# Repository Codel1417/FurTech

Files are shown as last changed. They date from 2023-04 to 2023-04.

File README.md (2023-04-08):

# FurTech

These are the files for a fursuit I am planning on making. I wanted eye displays for more expression, but then realized I cant see through the displays, Stereo cameras and an AR headset will be used for vision. The cameras will be hidden in the eyebrows. The jetson nano will handle stereo correction and managing the various sensors and servos. Once I have the hardware needed I will begin working on software. Base features are vision and ears reacting to sound. Then eye tracking using the cameras and opencv.

## Goals

* Eye Displays
* Ears which react to motion and environment
* Moving mouth to my voice
* Headpat detection and reactions
* Active cooling fan
* Stereo forward cameras
* AR/VR display for vision
* Eye Tracking (Vision or internal camera)
* No spaghetti 

## Hardware Features

Sensors connect over I2C

### Power Supply

* USB PD in @8-20V
* 3 5V 5A Linear Regulators
* Current Monitoring over I2C

### Sensors

* I2C Multiplexor
* Temperature Sensor
* 9-Axis IMU
* 5 Touch Sensors
* Cooling fan for comfort

### Ear Breakout

* Servo power switch
* i2C PWM Driver
* Mic/ADC input

### Display Driver

* 2 Display Connections
* Single output connection

### Jetson Nano Breakout

* I2C In
* Display SPI in
* Power in

## Other Hardware

* Nvidia Jetson Nano
* Nreal Air
* Stereo Cameras 1080P@60
* Usb PD battery
* 2x MatrixOrbital EVE3/4 displays
* 6x SG90 Servos

## 3D Printer STLs

* [https://www.thingiverse.com/thing:717901](https://www.thingiverse.com/thing:717901)

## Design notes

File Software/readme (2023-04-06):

Vision will be handled using GStreamer and OpenCV, in python. After coding and getting to a functional point I may switch to C/C++ for reduced power consumption.

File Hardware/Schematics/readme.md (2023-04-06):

The schematics were designed in [KiCad](https://www.kicad.org/) and use a consistent Resistor/Capacitor/LED size of 0603/1608 for ease of hand soldering. The AutoRouter plugin was used for data and low current traces. JST connectors are used to connect each board together.

Why split the boards? I was concerned about limited space inside the head so smaller boards let me contour the shape of the fursuit to reduce cable lengths and reduce the need to upscale the head. Smaller boards also allows for cheaper at con component swap out if something breaks.

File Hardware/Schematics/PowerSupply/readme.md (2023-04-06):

The original design was for an external 18650 battery pack but due to safety concerns I switched to USB C and premade packs.

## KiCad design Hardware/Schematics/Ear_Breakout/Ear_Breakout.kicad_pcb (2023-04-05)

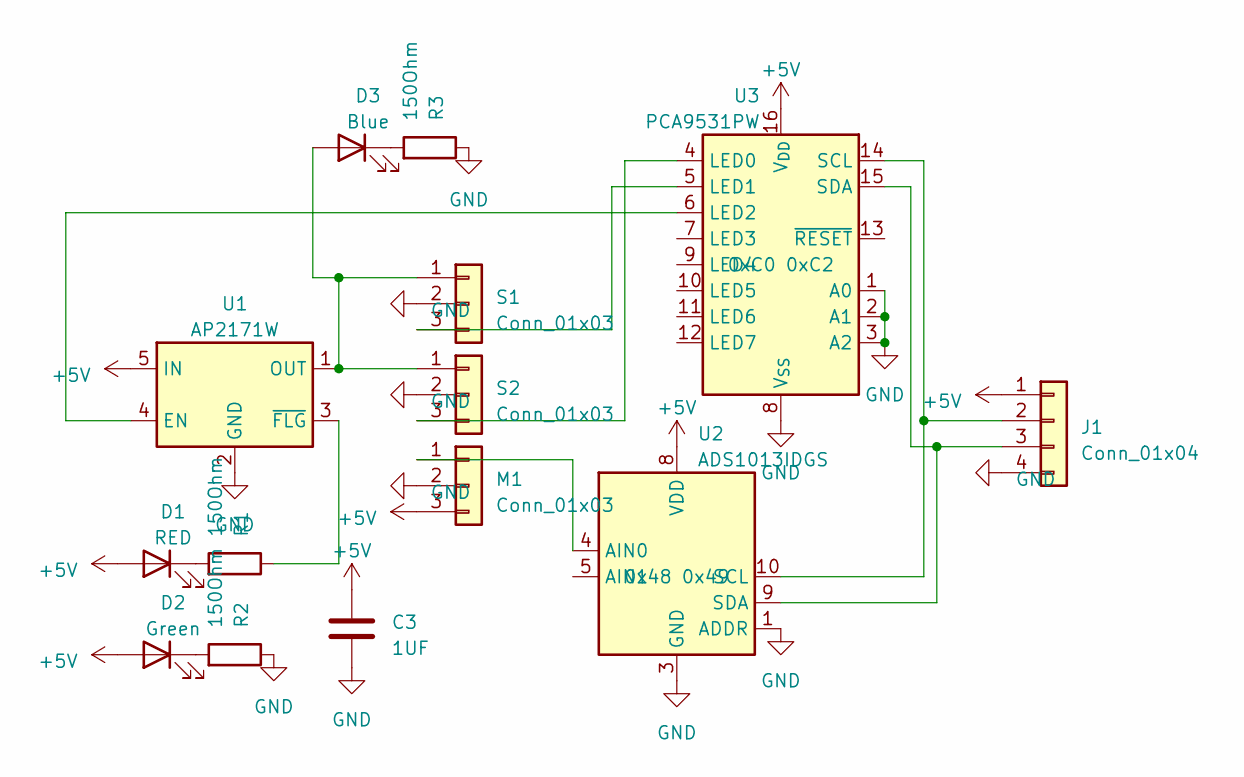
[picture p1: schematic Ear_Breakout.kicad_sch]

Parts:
C3: 1UF; C_0603_1608Metric_Pad1.08x0.95mm_HandSolder
D1: RED; LED_0603_1608Metric_Pad1.05x0.95mm_HandSolder
D2: Green; LED_0603_1608Metric_Pad1.05x0.95mm_HandSolder
D3: Blue; LED_0603_1608Metric_Pad1.05x0.95mm_HandSolder
J1: Conn_01x04; JST_EH_S4B-EH_1x04_P2.50mm_Horizontal
M1: Conn_01x03; PinHeader_1x03_P2.54mm_Horizontal
R1, R2, R3: 150Ohm; R_0603_1608Metric_Pad0.98x0.95mm_HandSolder
S1, S2: Conn_01x03; PinHeader_1x03_P2.54mm_Horizontal
U1: AP2171W; SOT-23-5
U2: ADS1013IDGS; TSSOP-10_3x3mm_P0.5mm
U3: PCA9531PW; TSSOP-16_4.4x5mm_P0.65mm

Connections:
+5V: C3.1, D1.2 (A), D2.2 (A), J1.1, M1.3, U1.5 (IN), U2.8 (VDD), U3.16 (V_{DD})
GND: C3.2, J1.4, M1.2, R2.1, R3.1, S1.2, S2.2, U1.2 (GND), U2.1 (ADDR), U2.3 (GND), U3.1 (A0), U3.2 (A1), U3.3 (A2), U3.8 (V_{SS})
unnamed: D1.1 (K), R1.2
unnamed: D2.1 (K), R2.2
unnamed: D3.2 (A), S1.1, S2.1, U1.1 (OUT)
unnamed: D3.1 (K), R3.2
unnamed: J1.2, U2.10 (SCL), U3.14 (SCL)
unnamed: J1.3, U2.9 (SDA), U3.15 (SDA)
unnamed: M1.1, U2.4 (AIN0)
unnamed: S1.3, U3.5 (LED1)
unnamed: S2.3, U3.4 (LED0)
unnamed: U1.4 (EN), U3.6 (LED2)
unnamed: R1.1, U1.3 (~FLG)

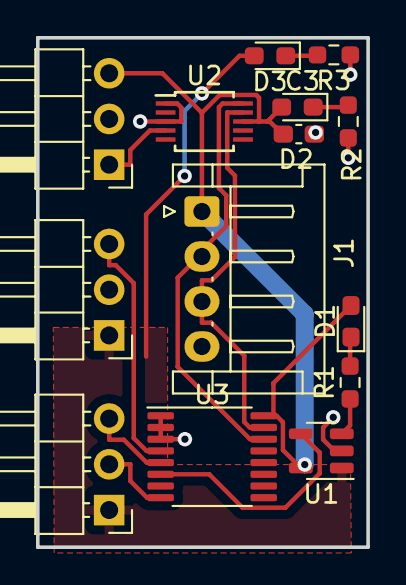
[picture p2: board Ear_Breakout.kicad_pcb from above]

Board: 2 copper layers, 18.3 x 28.3 mm, 14 parts (0 on the bottom side), 13 nets.

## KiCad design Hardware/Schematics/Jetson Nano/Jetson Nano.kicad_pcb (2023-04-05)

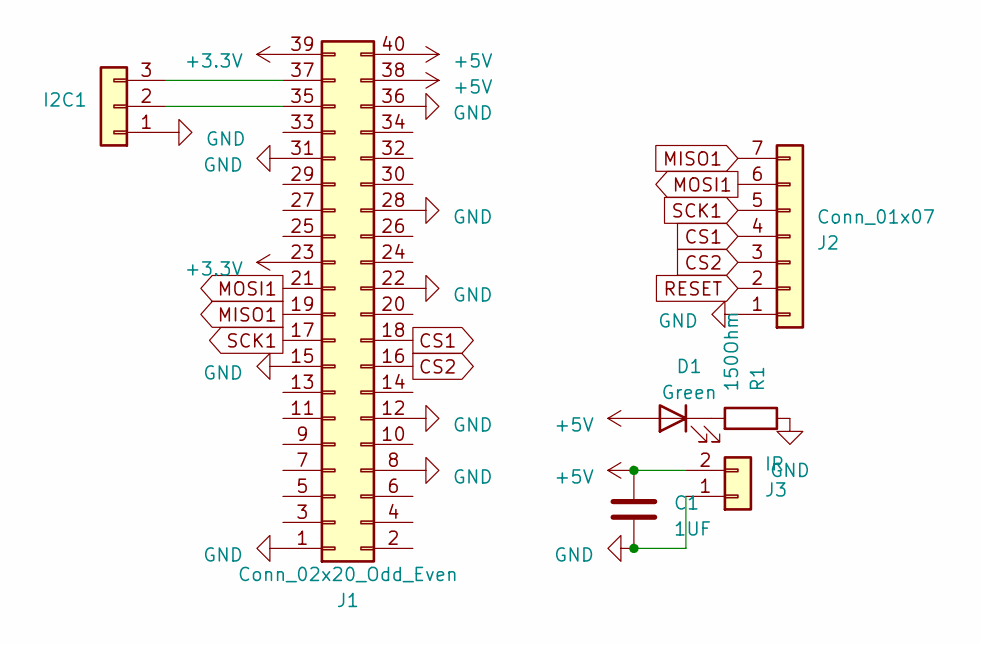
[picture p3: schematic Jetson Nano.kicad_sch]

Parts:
C1: 1UF; C_0603_1608Metric_Pad1.08x0.95mm_HandSolder
D1: Green; LED_0603_1608Metric_Pad1.05x0.95mm_HandSolder
I2C1: Conn_01x04; JST_EH_S3B-EH_1x03_P2.50mm_Horizontal
J1: Conn_02x20_Odd_Even; PinSocket_2x20_P2.54mm_Vertical
J2: Conn_01x07; JST_EH_S7B-EH_1x07_P2.50mm_Horizontal
J3: IR; JST_EH_S2B-EH_1x02_P2.50mm_Horizontal
R1: 150Ohm; R_0603_1608Metric_Pad0.98x0.95mm_HandSolder

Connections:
+3.3V: J1.23, J1.39
+5V: C1.1, D1.2 (A), J1.38, J1.40, J3.2
CS1: J1.18, J2.4
CS2: J1.16, J2.3
GND: C1.2, I2C1.1, J1.1, J1.8, J1.12, J1.15, J1.22, J1.28, J1.31, J1.36, J2.1, J3.1, R1.1
MISO1: J1.19, J2.7
MOSI1: J1.21, J2.6
unnamed: D1.1 (K), R1.2
unnamed: I2C1.2, J1.35
unnamed: I2C1.3, J1.37
RESET: J2.2
SCK1: J1.17, J2.5

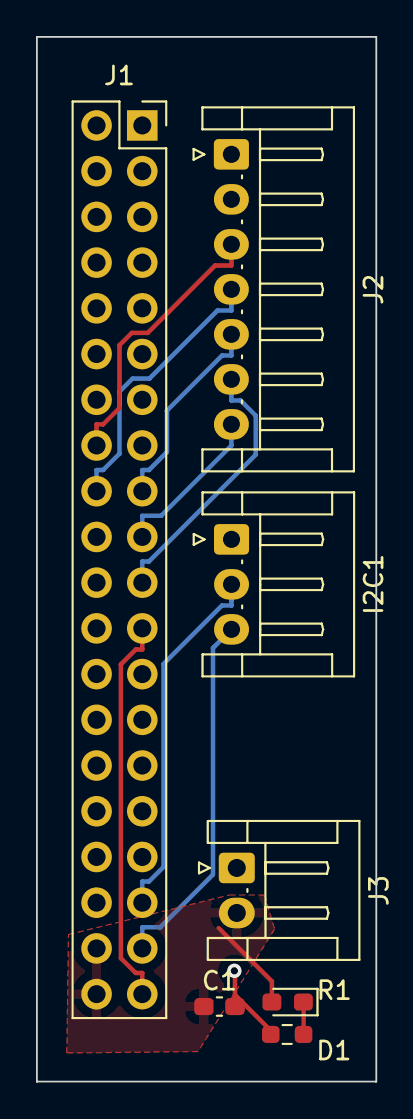
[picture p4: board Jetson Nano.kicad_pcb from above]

Board: 2 copper layers, 18.9 x 58.0 mm, 7 parts (0 on the bottom side), 11 nets.

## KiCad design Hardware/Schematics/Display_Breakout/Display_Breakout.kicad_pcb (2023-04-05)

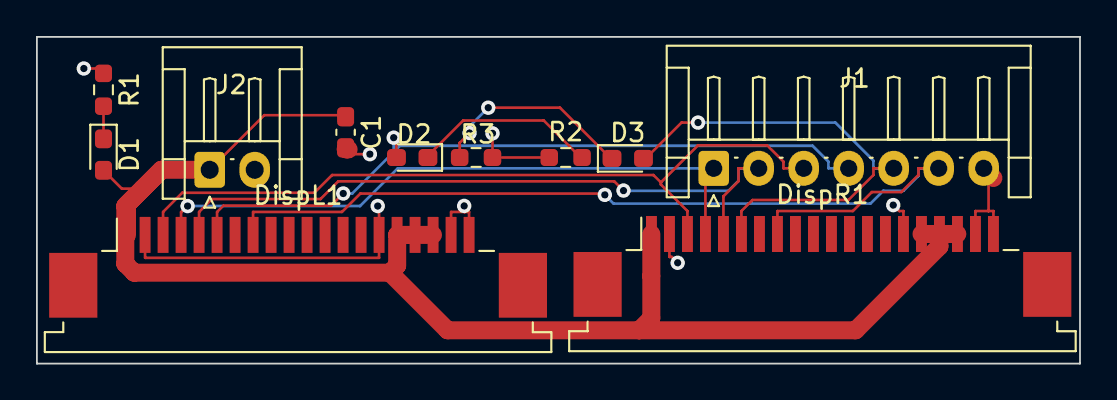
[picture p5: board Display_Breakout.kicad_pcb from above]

Board: 2 copper layers, 57.9 x 18.1 mm, 11 parts (0 on the bottom side), 11 nets.

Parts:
C1: 4.7uf; C_0603_1608Metric_Pad1.08x0.95mm_HandSolder
D1: Green; LED_0603_1608Metric_Pad1.05x0.95mm_HandSolder
D2, D3: Blue; LED_0603_1608Metric_Pad1.05x0.95mm_HandSolder
DispL1: Conn_02x10_Odd_Even; TE_2-84952-0_1x20-1MP_P1.0mm_Horizontal
DispR1: Conn_02x10_Odd_Even; TE_2-84952-0_1x20-1MP_P1.0mm_Horizontal
J1: Conn_01x07; JST_EH_S7B-EH_1x07_P2.50mm_Horizontal
J2: Conn_01x02; JST_EH_S2B-EH_1x02_P2.50mm_Horizontal
R1, R2, R3: 150Ohm; R_0603_1608Metric_Pad0.98x0.95mm_HandSolder

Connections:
+5V: C1.1, D1.2 (A), DispL1.1, DispL1.16, DispL1.17, DispL1.18, DispR1.1, DispR1.16, DispR1.17, DispR1.18, J2.1
CS1: D2.2 (A), DispL1.6, J1.4
CS2: D3.2 (A), DispR1.6, J1.5
GND: C1.2, DispL1.2, DispL1.15, DispL1.19, DispL1.20, DispR1.2, DispR1.15, DispR1.19, DispR1.20, J1.7, J2.2, R1.1, R2.1, R3.1
MISO1: DispL1.4, DispR1.4, J1.1
MOSI1: DispL1.5, DispR1.5, J1.2
unnamed: D1.1 (K), R1.2
unnamed: D2.1 (K), R2.2
unnamed: D3.1 (K), R3.2
RESET: DispL1.8, DispR1.8, J1.6
SCK1: DispL1.3, DispR1.3, J1.3

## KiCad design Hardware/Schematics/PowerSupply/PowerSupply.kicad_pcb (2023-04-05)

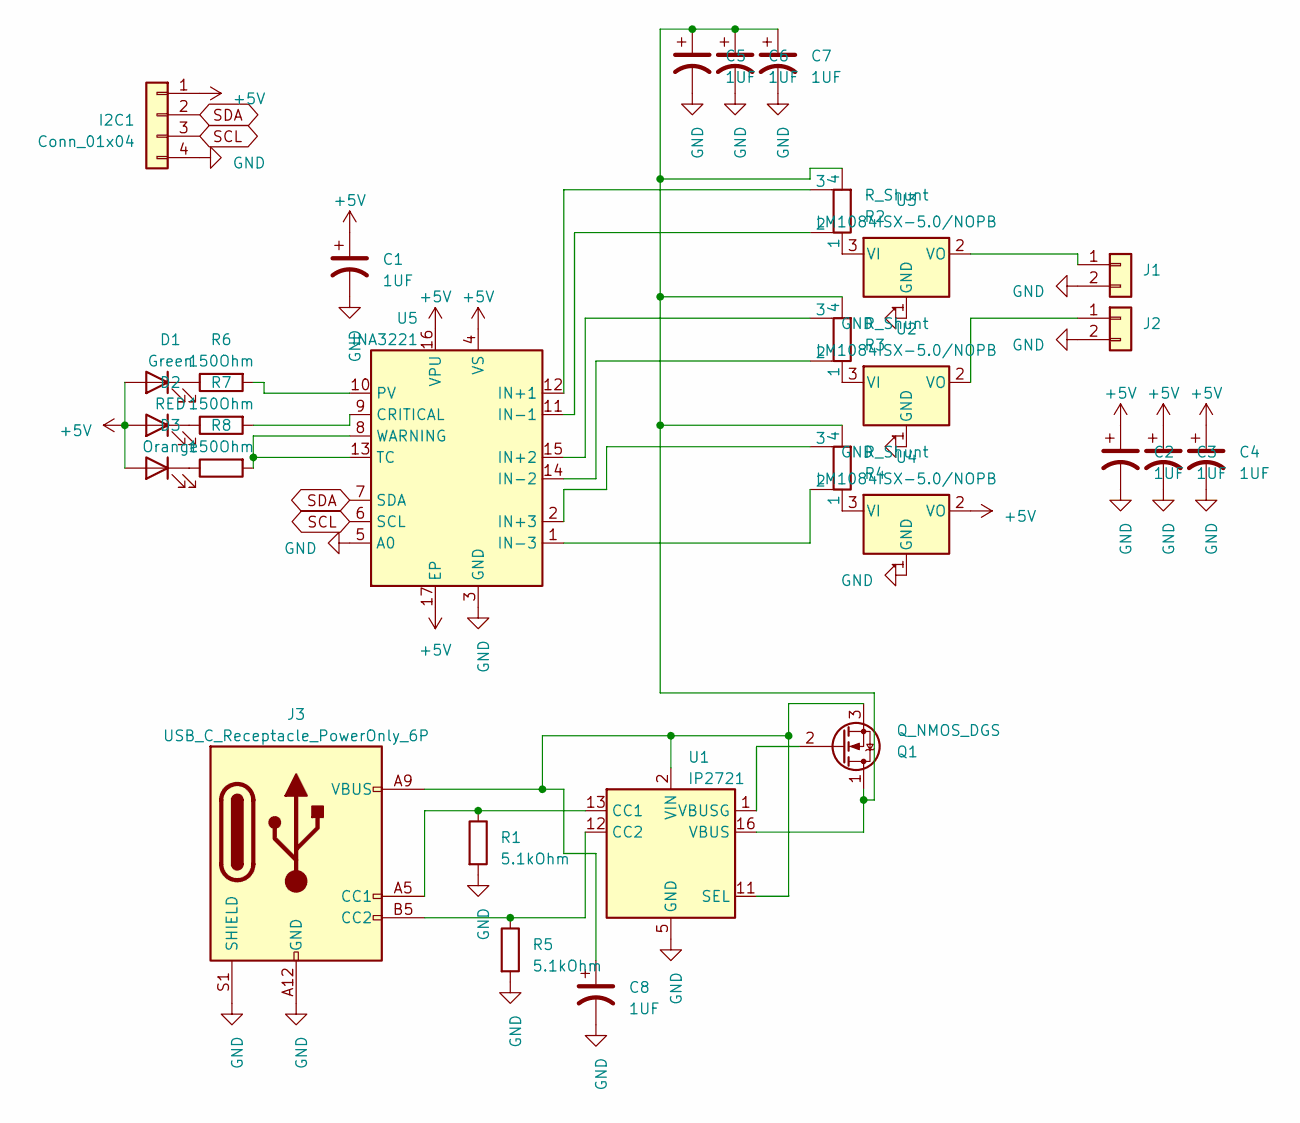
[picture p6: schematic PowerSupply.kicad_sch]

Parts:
C1, C2, C3, C4, C5, C6, C7, C8: 1UF; C_0603_1608Metric_Pad1.08x0.95mm_HandSolder
D1: Green; LED_0603_1608Metric_Pad1.05x0.95mm_HandSolder
D2: RED; LED_0603_1608Metric_Pad1.05x0.95mm_HandSolder
D3: Orange; LED_0603_1608Metric_Pad1.05x0.95mm_HandSolder
I2C1: Conn_01x04; JST_EH_S4B-EH_1x04_P2.50mm_Horizontal
J1, J2: JST_EH_S2B-EH_1x02_P2.50mm_Horizontal
J3: USB_C_Receptacle_PowerOnly_6P; USB_C_Receptacle_GCT_USB4135-GF-A_6P_TopMnt_Horizontal
Q1: Q_NMOS_DGS; TO-252-3_TabPin2
R1, R5: 5.1kOhm; R_0603_1608Metric
R2, R3, R4: R_Shunt; R_Shunt_Ohmite_LVK12
R6, R7, R8: 150Ohm; R_0603_1608Metric
U1: IP2721; TSSOP-16_4.4x5mm_P0.65mm
U2, U3, U4: LM1084ISX-5.0/NOPB; TO-263-3_TabPin2
U5: INA3221; Texas_RGV_S-PVQFN-N16_EP2.1x2.1mm

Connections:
+5V: C1.1, C2.1, C3.1, C4.1, D1.2 (A), D2.2 (A), D3.2 (A), I2C1.1, U4.2 (VO), U5.4 (VS), U5.16 (VPU), U5.17 (EP)
GND: C1.2, C2.2, C3.2, C4.2, C5.2, C6.2, C7.2, C8.2, I2C1.4, J1.2, J2.2, J3.A12 (GND), J3.B12 (GND), J3.S1 (SHIELD), R1.2, R5.2, U1.5 (GND), U2.1 (GND), U3.1 (GND), U4.1 (GND), U5.3 (GND), U5.5 (A0)
unnamed: D1.1 (K), R6.1
unnamed: D2.1 (K), R7.1
unnamed: D3.1 (K), R8.1
unnamed: J1.1, U3.2 (VO)
unnamed: J2.1, U2.2 (VO)
unnamed: J3.A5 (CC1), R1.1, U1.13 (CC1)
unnamed: J3.B5 (CC2), R5.1, U1.12 (CC2)
unnamed: C5.1, C6.1, C7.1, Q1.1 (D), R2.4, R3.4, R4.4, U1.16 (VBUS)
unnamed: Q1.2 (G), U1.1 (VBUSG)
unnamed: C8.1, J3.A9 (VBUS), J3.B9 (VBUS), Q1.3 (S), U1.2 (VIN), U1.11 (SEL)
unnamed: R3.1, U2.3 (VI)
unnamed: R2.1, U3.3 (VI)
unnamed: R4.1, U4.3 (VI)
unnamed: R7.2, U5.9 (CRITICAL)
unnamed: R2.3, U5.12 (IN+1)
unnamed: R3.3, U5.15 (IN+2)
unnamed: R4.3, U5.2 (IN+3)
unnamed: R2.2, U5.11 (IN-1)
unnamed: R3.2, U5.14 (IN-2)
unnamed: R4.2, U5.1 (IN-3)
unnamed: R6.2, U5.10 (PV)
unnamed: R8.2, U5.8 (WARNING), U5.13 (TC)
SCL: I2C1.3, U5.6 (SCL)
SDA: I2C1.2, U5.7 (SDA)

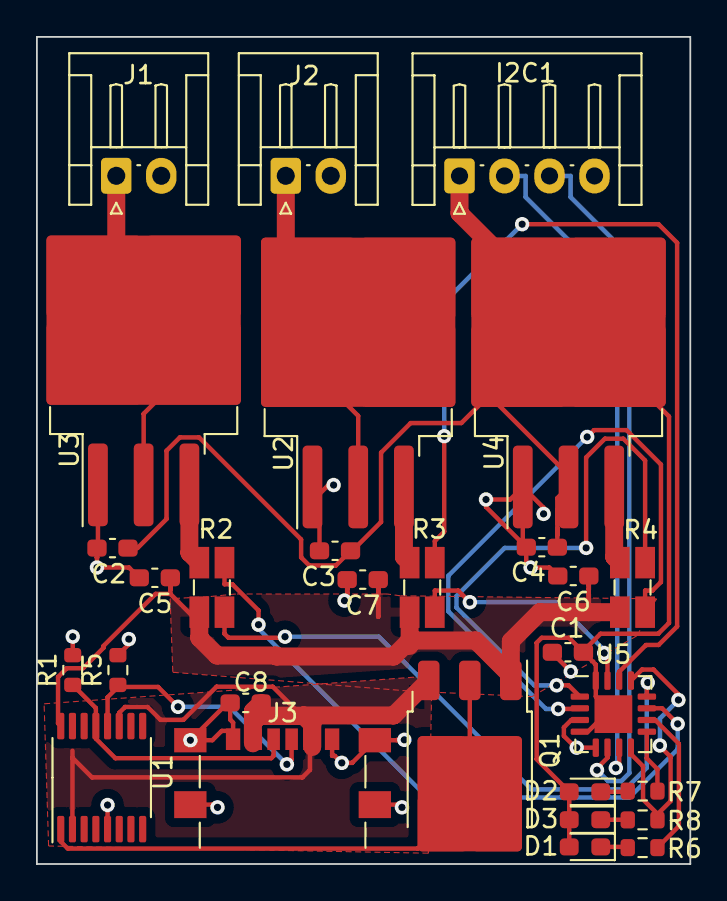
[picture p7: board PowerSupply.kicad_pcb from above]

Board: 2 copper layers, 36.3 x 46.0 mm, 29 parts (0 on the bottom side), 26 nets.

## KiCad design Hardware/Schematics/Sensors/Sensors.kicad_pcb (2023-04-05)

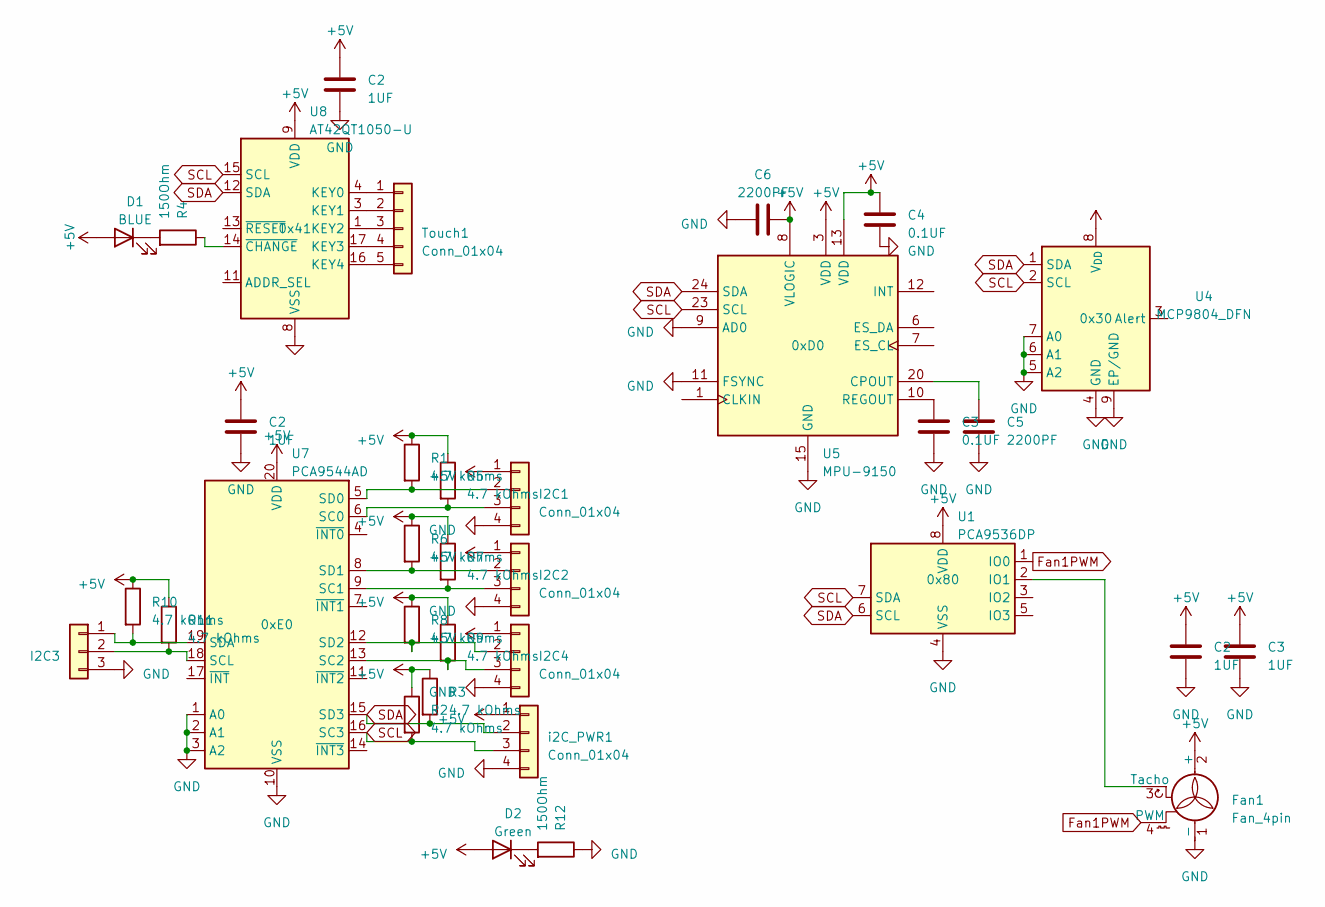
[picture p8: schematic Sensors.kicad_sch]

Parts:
C2: 1UF; C_0603_1608Metric_Pad1.08x0.95mm_HandSolder
C3, C4: 0.1UF; C_0603_1608Metric_Pad1.08x0.95mm_HandSolder
C5, C6: 2200PF; C_0603_1608Metric_Pad1.08x0.95mm_HandSolder
D1: BLUE; LED_0603_1608Metric_Pad1.05x0.95mm_HandSolder
D2: Green; LED_0603_1608Metric_Pad1.05x0.95mm_HandSolder
Fan1: Fan_4pin; FanPinHeader_1x04_P2.54mm_Vertical
I2C1, I2C2, I2C4: Conn_01x04; JST_EH_S4B-EH_1x04_P2.50mm_Horizontal
I2C3: Conn_01x03; JST_EH_S3B-EH_1x03_P2.50mm_Horizontal
R1, R2, R3, R5, R6, R7, R8, R9, R10, R11: 4.7 kOhms; R_0603_1608Metric
R4, R12: 150Ohm; R_0603_1608Metric_Pad0.98x0.95mm_HandSolder
Touch1: Conn_01x04; PinHeader_1x05_P2.54mm_Horizontal
U1: PCA9536DP; TSSOP-8_3x3mm_P0.65mm
U4: MCP9804_DFN; DFN-8-1EP_3x2mm_P0.5mm_EP1.7x1.4mm
U5: MPU-9150; InvenSense_QFN-24_4x4mm_P0.5mm
U7: PCA9544AD; TSSOP-20_4.4x6.5mm_P0.65mm
U8: AT42QT1050-U; VQFN-20-1EP_3x3mm_P0.45mm_EP1.55x1.55mm
i2C_PWR1: Conn_01x04; JST_EH_S4B-EH_1x04_P2.50mm_Horizontal

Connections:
Fan1PWM: Fan1.4 (PWM), U1.1 (IO0)
GND: C2.2, C3.2, C4.2, C5.2, C6.2, Fan1.1 (-), I2C1.4, I2C2.4, I2C3.3, I2C4.4, R12.1, U1.4 (VSS), U4.4 (GND), U4.5 (A2), U4.6 (A1), U4.7 (A0), U4.9 (EP/GND), U5.9 (AD0), U5.11 (FSYNC), U5.15 (GND), U5.17 (GND), U5.18 (GND), U7.1 (A0), U7.2 (A1), U7.3 (A2), U7.10 (VSS), U8.8 (VSS), U8.21 (VSS), i2C_PWR1.4; also elsewhere on the board
unnamed: D1.1 (K), R4.2
unnamed: D2.1 (K), R12.2
unnamed: Fan1.3 (Tacho), U1.2 (IO1)
unnamed: I2C1.2, R1.2, U7.5 (SD0)
unnamed: I2C1.3, R5.2, U7.6 (SC0)
unnamed: I2C2.2, R6.2, U7.8 (SD1)
unnamed: I2C2.3, R7.2, U7.9 (SC1)
unnamed: I2C3.1, R10.2, U7.19 (SDA)
unnamed: I2C3.2, R11.2, U7.18 (SCL)
unnamed: I2C4.2, R8.2, U7.12 (SD2)
unnamed: I2C4.3, R9.2, U7.13 (SC2)
unnamed: Touch1.1, U8.4 (KEY0)
unnamed: Touch1.2, U8.3 (KEY1)
unnamed: Touch1.3, U8.1 (KEY2)
unnamed: Touch1.4, U8.17 (KEY3)
unnamed: Touch1.5, U8.16 (KEY4)
unnamed: C5.1, U5.20 (CPOUT)
unnamed: R4.1, U8.14 (~CHANGE)
SCL: R2.2, U1.7 (SDA), U4.2 (SCL), U5.23 (SCL), U7.16 (SC3), U8.15 (SCL), i2C_PWR1.3
SDA: R3.2, U1.6 (SCL), U4.1 (SDA), U5.24 (SDA), U7.15 (SD3), U8.12 (SDA), i2C_PWR1.2

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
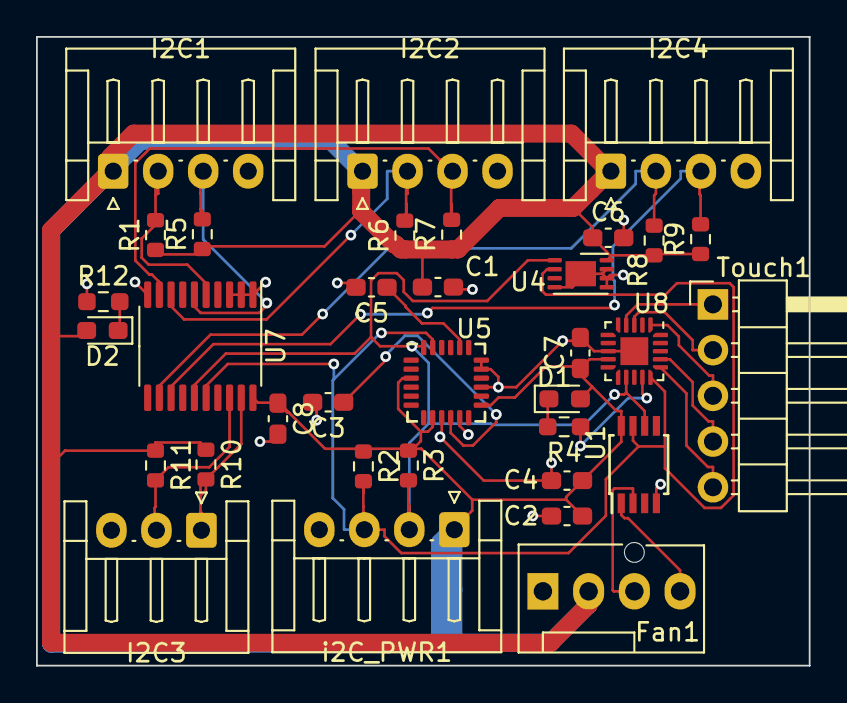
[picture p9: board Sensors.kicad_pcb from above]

Board: 2 copper layers, 42.9 x 34.9 mm, 34 parts (0 on the bottom side), 24 nets.

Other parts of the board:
C1, C7, C8: 1UF; C_0603_1608Metric_Pad1.08x0.95mm_HandSolder

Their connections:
GND: C1.2, C7.2, C8.2; also elsewhere on the board
